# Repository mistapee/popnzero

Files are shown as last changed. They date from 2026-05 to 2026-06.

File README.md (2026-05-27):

s-l1600 (4)
20gbp on ebay. sourcing the keycaps was a proper arse ache frankly. Ebay link at bottom.

# popnzero
Pop'n controller set out for 1u keys

s-l1600 (2)

We went and ordered the pcb+plate design with RGB LEDs and keyswitch LEDs, the design is 13.7cmx7.7cm and we're very happy with the results. The layout is angled the same as other controllers, but with appropriate spacing to find your way around the pad while gaming - for instance, the fight board caps we used on the larger controller look amazing on this, but, it loses the spacing and actually playing with it is a nightmare turning it in to a novelty which is everything we wanted to avoid.



GPIO used, for technical infos for GP2040-CE or whatever:
0 - aux switch
1 - rgb led
2 - btn8
3 - led 8
4 - btn 9
5 - led 9
6 - btn 7
7 - led 7
8 - btn 6
9 - led 6
10 - btn 5
11 - led 5
12 - btn 4
13 - led 4
14 - btn 3
15 - led 3
26 - btn 1
27 - led 1
28 - btn 2
29 - led 2

5v - to rgb leds
gnd - connected to gnd plane
3v3 - unused



You can buy cheap from OpenRhythmUK on Ebay (https://www.ebay.com/sch/i.html?_ssn=openrhythmuk) as usual. As much as the international shipping fee can be (realistically you still couldn't find cheaper) I am more than reasonable and a lot make contact about creating a bundle for them where not only do I discount everything, usually adding 2 or 3 more controllers doesn't change the shipping fee. I've given away a lot of bonus items for my own entertainment

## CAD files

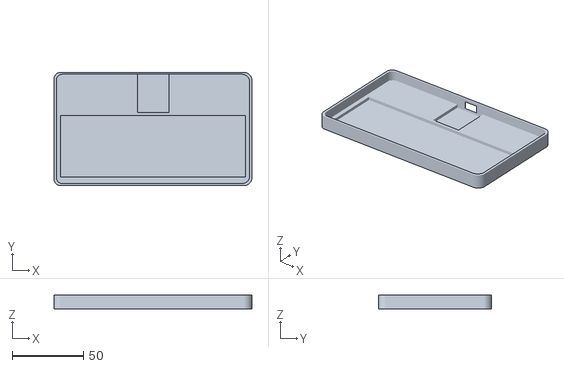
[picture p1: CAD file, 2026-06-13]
popn_zero_case-basic.stl
139.3 x 79.7 x 10.0

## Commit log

2026-03-17 added popnzero 3d case stl
    [popnZERO_with_mountholes_zeroholed.stl]
2026-06-13 basic case - see extended description for details
    I print this at 100.3% scale and the controller slides in nicely, other cases I print at 100.2% and obviously your settings may needs to differ, but, with this case being so thing and small the slightly more snug 100.2 can add a bit of a twist in to the case if the controller is not perfectly evenly pushed in to it. by going up to 100.3 it slides in nicely and doesn't grip unevenly to twist it.
    ALSO! a note that I will go in to more on other pages - the USB port involves bridging, and on my printer with high speed PLA, done in draft etc, I would get a slight gap in a single layer to the side of the bridged section. I solved this by TURNIN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
    [popn_zero_case-basic.stl]
